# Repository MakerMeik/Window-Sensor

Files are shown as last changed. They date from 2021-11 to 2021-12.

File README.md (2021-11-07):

# Window-Sensor

Project-Idea by Michael Dworkin: https://esp8266-server.de/Reedkontakt.html

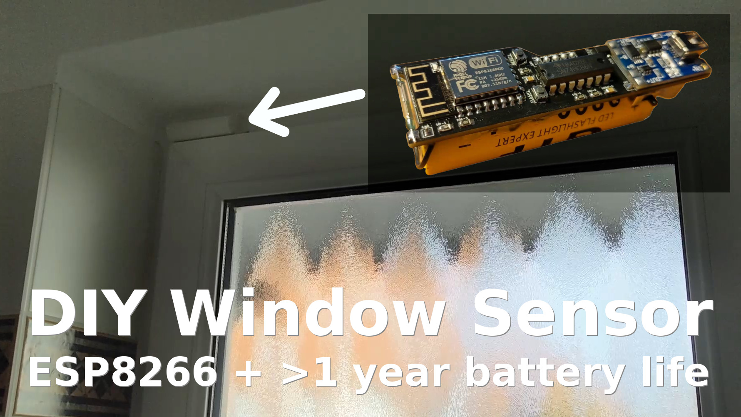
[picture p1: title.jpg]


Here you will find all the files you need to build an ESP8266-based window sensor whose battery will last for several years.  
Have a look at my video on Youtube:
https://youtu.be/vxbuO1zWo3w

Here you can find the code (ArduinoIDE/PlatformIO) for the microcontroller, the Gerber files for PCB ordering, the circuit simulation for CircuitJS and additional information.

## Required Components

1x ESP-12F  
1x 1000 uF Electrolytic Capacitor  
2x 100 nF Capacitor  
4x 10k Resistor (SMD 0805)  
1x 1M Resistor (SMD 0805)  
2x Switch Buttons (SMD 0805)  
1x HT7333 (SMD)  
1x Pin Header  
1x Reed Switch NO (normally open)  
1x 74HC86 (THT)  
1x TP4056  
1x Li-Ion 18650  
1x Magnet  
1x 3D-printed case (https://www.thingiverse.com/thing:5019573)  

## Links
KiCAD:  
https://www.kicad.org/  

CircuitJS:  
http://www.falstad.com/circuit/

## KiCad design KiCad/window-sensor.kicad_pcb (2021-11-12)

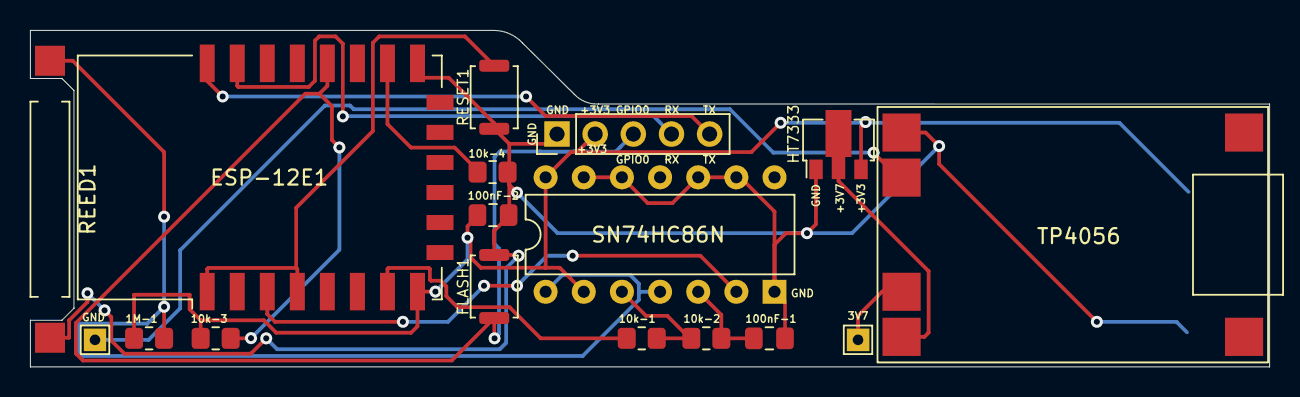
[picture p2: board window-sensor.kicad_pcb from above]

Board: 2 copper layers, 82.5 x 22.4 mm, 18 parts (1 on the bottom side), 14 nets.

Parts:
1M-1: 1M; R_0805_2012Metric_Pad1.20x1.40mm_HandSolder
3V7: TestPoint_THTPad_1.5x1.5mm_Drill0.7mm
10k-1, 10k-2, 10k-3, 10k-4: 10k; R_0805_2012Metric_Pad1.20x1.40mm_HandSolder
100nF-1, 100nF-2: 100nF; C_0805_2012Metric_Pad1.18x1.45mm_HandSolder
1000uF-1: 1000uF; CP_Elec_10x12.6
ESP-12E1: ESP-12E
FLASH1: SW_Push; SW_Push_SPST_NO_Alps_SKRK
GND: TestPoint_THTPad_1.5x1.5mm_Drill0.7mm
HT7333: HT75xx-1-SOT89; SOT-89-3
J1: Conn_01x05_Male; PinHeader_1x05_P2.54mm_Vertical
REED1: SW_Reed; SW_SPST_REED_CT10-XXXX-G4
RESET1: SW_Push; SW_Push_SPST_NO_Alps_SKRK
TP4056: TP4056
U3: 74HC86; DIP-14_W7.62mm

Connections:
+3V3: 1M-1.1, 10k-3.2, 100nF-2.1, 1000uF-1.1, ESP-12E1.8, HT7333.3, J1.2, U3.2
+3V8: 3V7.1, HT7333.2, TP4056.B+, TP4056.OUT+
EN: ESP-12E1.3, U3.6
GND: 10k-4.1, 100nF-1.2, 100nF-2.2, 1000uF-1.2, ESP-12E1.15, FLASH1.2, HT7333.1, J1.1, REED1.1, RESET1.1, TP4056.OUT-
GND1: GND.1, TP4056.B-
GPIO13: 10k-1.1, ESP-12E1.7
unnamed: 1M-1.2, REED1.2, U3.1, U3.4
unnamed: 10k-1.2, 10k-2.2, U3.3
unnamed: 10k-3.1, ESP-12E1.18, FLASH1.1, J1.3
unnamed: 10k-4.2, ESP-12E1.16
unnamed: 10k-2.1, 100nF-1.1, U3.5
unnamed: ESP-12E1.1, ESP-12E1.4, RESET1.2
unnamed: ESP-12E1.21, J1.4
unnamed: ESP-12E1.22, J1.5

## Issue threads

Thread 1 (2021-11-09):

Circuit PDF is Incorrect

dashdrum, 2021-11-09:
It seems to me that the PDF representation of the circuit is for another project.

MakerMeik, 2021-11-09:
Thanks for the hint, that was the simple schematic of a very early version I had made on D1-mini basis with two reed switches. The current circuit actually has nothing to do with it anymore. I have deleted the files.

Closed 2021-11-09.

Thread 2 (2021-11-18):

Cannot see it on the network

gadjet, 2021-11-18:
HI,
My PCBs arrived I setup platformIO for the first time and I think I've compiled it correctly and it writes the compiled code to the ESP but I cannot see it on my network.
I set the information in the secrets.h.template and saved it as secrets.h my MQTT server is an external one so I added "M20.cloudmqtt.com" as the MQTT server IP address, will this work?

If I move a magnet to the reed switch the blue led flashes and again as I move it away so I assume the ESP is powered and running it just doesn't seem to connect to my network, any ideas?
I also monitored my MQTT account to see if there were any messages received but there were none :-(

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
s?

MakerMeik, 2021-11-18:
The best thing to do first is to check if your ESP successfully connects to your router via Wifi. Since the router probably assigns the IP addresses automatically via DHCP, you should first comment out the line:

`// WiFi.config(ip, gateway, subnet);`

and only later define it as a fixed IP address in the router and ESP.
Unfortunately, I am not familiar with external MQTT servers. But if this works with your other (ESP-based?) devices, it should also work here.

If you don't get further, you can still output additional "Serial.println("...");" via RX/TX and your USB-to-TTL converter and debug it this way.

The blue flashing is the usual behavior when something changes at the reed switch.

By the way, I love the redesign of your PCB!

gadjet, 2021-11-18:
Thanks, it's all down to your video :-)
I think it is connecting but it's going offlline so quickly my router isn't showing it, I think I need to disable the sleep.
I have now seen a couple of messages on the MQTT cloud so it is connecting OK.

Thanks

gadjet, 2021-11-25:
It looks like setting it to a fixed IP address stops it connecting to my router, using DHCP means it connects OK but takes around 7 seconds to send the MQTT, I'm OK with that delay.

MakerMeik, 2021-11-25:
Of course, you also need to be able to assign a fixed IP to the device in your router. In my router (Fritzbox) I always connect first via DHCP, so that the ESP gets an automatic IP, and this I can then change to a fixed IP.
This is not only a matter of delay, but also the time it takes for the ESP to connect. Of course, the longer it takes, the more battery power is used. That is why you should consider changing it again.

gadjet, 2021-11-25:
I set the IP address in the router via DHCP then fixed it but it still won't connect at all, maybe it's my router that's causing the problem.  I have some other ideas about increasing battery life but still trying to work it out.

MakerMeik, 2021-11-25:
OK, and after you fixed the IP in the router, did you also fix it in ESP? Strange that something so basic causes problems.
But I'm happy if you have ideas for further optimization. Let me know if you have any new findings in this regard.

gadjet, 2021-11-25:
Yep I fixed it both, I have fixed IP addresses for other devices like Raspberry Pis etc. it's strange.
If my ideas bear fruit I'll let you know.

gadjet, 2021-11-28:
OK I would like to run this sensor on a single AA battery so I've designed a circuit using an MCP1640 to step up 1.5V to 3.3V and noticed the converter has an enable input on it so I was thinking of switching on the 3.3V to the ESP with another XOR gate acting as an inverter for the current enable signal and changing the pulse width to a vaule that allows the ESP to boot up and switch the enable pin from a GPIO pin also until the transmission is finished.
The problem with this is that the logic gates would need to be powered all the time therefore a higher battery voltage would be needed making the step-up converter redundant so if I use a single cell lithium with a voltage regulator as currently I could use a P channel MOSFET to switch on the ESP power from the logic gates triggered by the reed switch and hold on the power until finished.
The second way is by keeping it as it is now and using ESP-NOW to communicate which doesn't need an IP address from the router as it talks directly to another ESP, this would require a permenantly powered ESP as a receiver/bridge/gateway (https://www.youtube.com/watch?v=xPPdYvKbSFk) which could then send MQTT messages.
Using ESP-NOW you are looking at a transmission time of around 200mS from powerup to power down.
Using ESP-NOW would allow a smaller L-ION cell to be used to get a similar or better usage period.

Closed 2021-11-27.

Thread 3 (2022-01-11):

74HC86 not connected to vcc and gnd in "_Alternative PCB-Layout by Juergen"

cblank2, 2022-01-11:
in the "_Alternative PCB-Layout by Juergen" the 74HC86 has no power ;-(

pin 14 should be conntected to vcc
pin 7 should be connected to gnd

MakerMeik, 2022-01-11:
You're right, something has obviously really gone wrong here. It is the alternative design of a viewer. Unfortunately, I had not final tested that and apparently neither had he.
Have you already ordered the PCBs or have you found the error before. If you already have the PCBs, you could try connecting the correct pins with enamelled copper wire.
However, I believe that the rest of the pins on the 74HC86 are not connected properly either. I think I will remove the entire folder from Github and limit myself to my own design, which I have tested in depth and which is successfully in use in quite a few places in my house.
Sorry for the trouble.

cblank2, 2022-01-11:
Yes, i got some of the PCBs ;-(
i connected the missing pins with a simple copper wire and it seems to work

after i built my own 3d-printed case for it, i believe your original layout would fit better ;-(

I've a suggestion for the pcb: having another button on the board would not really raise complexity, but add some more flexibility for the "customer"
I made some other PCBs with an extra button, which will turn the "config-mode" on, if it's pressed during boot.
So a wifi-hotspot is enabled and you can make some settings via webserver (e.g. set wifi-config) or even upgrade the software
(just a thought)

MakerMeik, 2022-01-11:
Thanks, that's a really interesting suggestion. I will consider this for my future projects. However, this project is finished for me, apart from bugs of course, if any are still found.

Closed 2022-01-11.

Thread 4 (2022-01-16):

Version 2 PCB reduced size

gadjet, 2022-01-16:
Not an issue really just an update on my second revision of my PCB
https://github.com/gadjet/Window-Door-Sensor-V2
I also have another version in the works even smaller with a bit more functionality.

teuchezh, 2022-02-14:
I wonder if your version is fully compatible with the version from this repository in terms of hardware (in the sense of components) and software?
In your version, does the battery connect directly or does it involve connecting a charging module, for example, the same TP4056?

gadjet, 2022-02-14:
My version contains no charging circuitry, as I use ESP-NOW to transmit the data packet which doesn't require a connection to a router and only takes around 500mS to transmit therefore a 500mAh battery should last over a year depending on usage so I don't need the recharging capability.
The circuit is the same although the components are different as I use single gate ICs instead of a quad gate chip.

MakerMeik, 2022-02-14:
I love your project! It's totally amazing and I didn't expect you to optimize it with such perseverance. I've already discovered the even further scaled down version 3 and I couldn't believe my eyes. Awesome!

gadjet, 2022-02-14:
Thanks, I think I may have become addicted to  your window sensor 😁 I have a version 4 that has the position for a button and a bme280 I2C sensor for temp/humidity/pressure, I'm using version 3 to remotely monitor outside Temp.  It's been running for 3 weeks transmitimg every 15 mins and the battery has only dropped 0.1v

Closed 2022-03-29.

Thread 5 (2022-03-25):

New Version 5 PCB

gadjet, 2022-03-25:
Hi,
Just thought I'd let you know version 5 is now working, small PCB with additional button trigger to be used as doorbell? or maybe vibration switch?
Quiescent now down to 3 to 5 uA depending on usage
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

Details @ https://github.com/gadjet/Window-Door-sensor-Version-5

MakerMeik, 2022-03-29:
It's so impressive where you've taken this project in the meantime. I've updated the Github- and Blog-links to your new version in my video description and can only hope that future viewers of the video will find this great evolution. Unbelivable!

In fact, I really need to do a follow up video on this. At the moment I unfortunately lack the time, but I think I will have your circuit manufactured in due course and rebuild. Your circuit is the perfect basis for all conceivable other battery-powered projects based on ESP8266. Thank you for sharing your work with the community.

gadjet, 2022-03-30:
Thanks very much for the kind words, I really love making stuff and it's even better when others also find it useful.
I would be happy to send you a PCB if you like, if you are on Facebook I'm a member of the ESP8266/ESP32 group, join and then you can message me direct?

Closed 2024-01-24.

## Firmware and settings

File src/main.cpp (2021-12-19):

#include <Arduino.h>
#include <ESP8266WiFi.h>
#include <PubSubClient.h>
#include <secrets.h>

WiFiClient espClient;
PubSubClient client(espClient);

EspClass ESPm;

const char* ssid = SECRET_SSID;
const char* password = SECRET_PASS;
const char* mqtt_server = "192.168.1.xyz"; // The IP-Adress of your MQTT-Server
const unsigned int mqtt_port = 1883;
const char* mqtt_user = "admin";
const char* mqtt_pass = SECRET_MQTT_PASS;

IPAddress ip(192, 168, 1, FIXED_IP); // If your router reserves a fixed IP for your ESP, enter it here. Alternatively, you can also use the placeholder of the "secrets.h" file.
IPAddress gateway(192, 168, 1, 1);
IPAddress subnet(255, 255, 255, 0);

ADC_MODE(ADC_VCC);
int voltage = 999;

String clientId = "iot-Bathroom";

bool status; // Windowsstatus - 0 = open / 1 = closed
int counter = 0;

void setup_wifi(){  // Start WiFi-Connection
  WiFi.config(ip, gateway, subnet);  // Disable this line for the automatic assignment of the IP address by the DHCP of your router
  WiFi.begin(ssid, password);
  while (WiFi.status() != WL_CONNECTED)
  {
    delay(500);
    counter++;
    if (counter > 20) {
      ESP.deepSleep(0);
    }
  }
  counter = 0;
}

void reconnect() {
  // Loop until we're reconnected
  while (!client.connected()) {
    if (client.connect(clientId.c_str(),mqtt_user,mqtt_pass)) {
    } else {
      counter++;
      delay(500);
    }
    if (counter > 20) {
      ESP.deepSleep(0);
    }
  }
  counter = 0;
}

void setup() {
  setup_wifi();
  client.setServer(mqtt_server, mqtt_port);
  pinMode(13,INPUT);
  pinMode(D0, WAKEUP_PULLUP);
}

void loop() {
  if (!client.connected()) {
    reconnect();
  }
  client.loop();
  voltage = ESP.getVcc();
  status = digitalRead(13);
  if (status == 0) {
    client.publish("Windows/Bathroom", "open", true);
    client.publish("Windows/Bathroom/Vcc", String(voltage).c_str());
  } else {
    client.publish("Windows/Bathroom", "closed", true);
    client.publish("Windows/Bathroom/Vcc", String(voltage).c_str());
  }
  client.subscribe("Windows/Bathroom");
  delay(200);
  
  ESP.deepSleep(0);
  delay(200);
}

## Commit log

2021-10-16 Battery-Spreadsheet added
    [Battery consumption.xlsx]
2021-10-20 Drillfile added
    [window-sensor.drl]
2021-11-07 Circuit corrected. Pullup now at GPIO0 instead of GPIO2.
    [window-sensor-B_Cu.gbr, window-sensor-B_Mask.gbr, window-sensor-B_Paste.gbr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]
2021-11-09 Unrelated files deleted
    [window-sensor-circuit_RevA.fzz]
2021-11-12 Alternative PCB-Layout by yt-viewer Juergen
    [window-sensor-B_Cu.gbr, window-sensor-B_Mask.gbr, window-sensor-B_Paste.gbr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]
2022-01-11 74HC86 was connected incorrectly
    Entire design was untested and omitted since it is a duplicate anyway. Alternative design is welcome to continue as a fork of the main project.
    [window-sensor-B_Cu.gbr, window-sensor-B_Mask.gbr, window-sensor-B_Paste.gbr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]

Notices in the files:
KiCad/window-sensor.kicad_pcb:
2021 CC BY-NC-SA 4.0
